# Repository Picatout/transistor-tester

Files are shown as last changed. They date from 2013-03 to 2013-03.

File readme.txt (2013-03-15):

Il s'agit d'un vérificateur de transistor bi-jonction réalisé avec un PIC10F202-I/P

La polarité et l'état du transistor est indiqué par 2 LEDs

Lorsque la LED verte clignote il 'sagit d'un NPN
Lorsque la LED rouge clignote il s'agit d'un PNP
Si les 2 clignotent en alternance il y a un court-circuit entre émetteur et collecteur
Si aucune LED n'allume le transistor est défectueux ou ce n'est pas un transistor bi-jonction.
Si on inverse collecteur et émetteur la LED clignote quand même mais plus faiblement.
Ceci n'indique pas une défectuosité du transistor mais plutôt une certaine symétrie entre les 2 
jonctions, base-collectteur et base-émetteur.  Cette symétrie est particulièrement visible sur
les transistors de commutation ZTX649 (NPN) et ZTX749 (PNP) alors que la LED clignote
avec presqu'autant d'intensité lorsqu'on inverse les émetteurs et collecteurs.

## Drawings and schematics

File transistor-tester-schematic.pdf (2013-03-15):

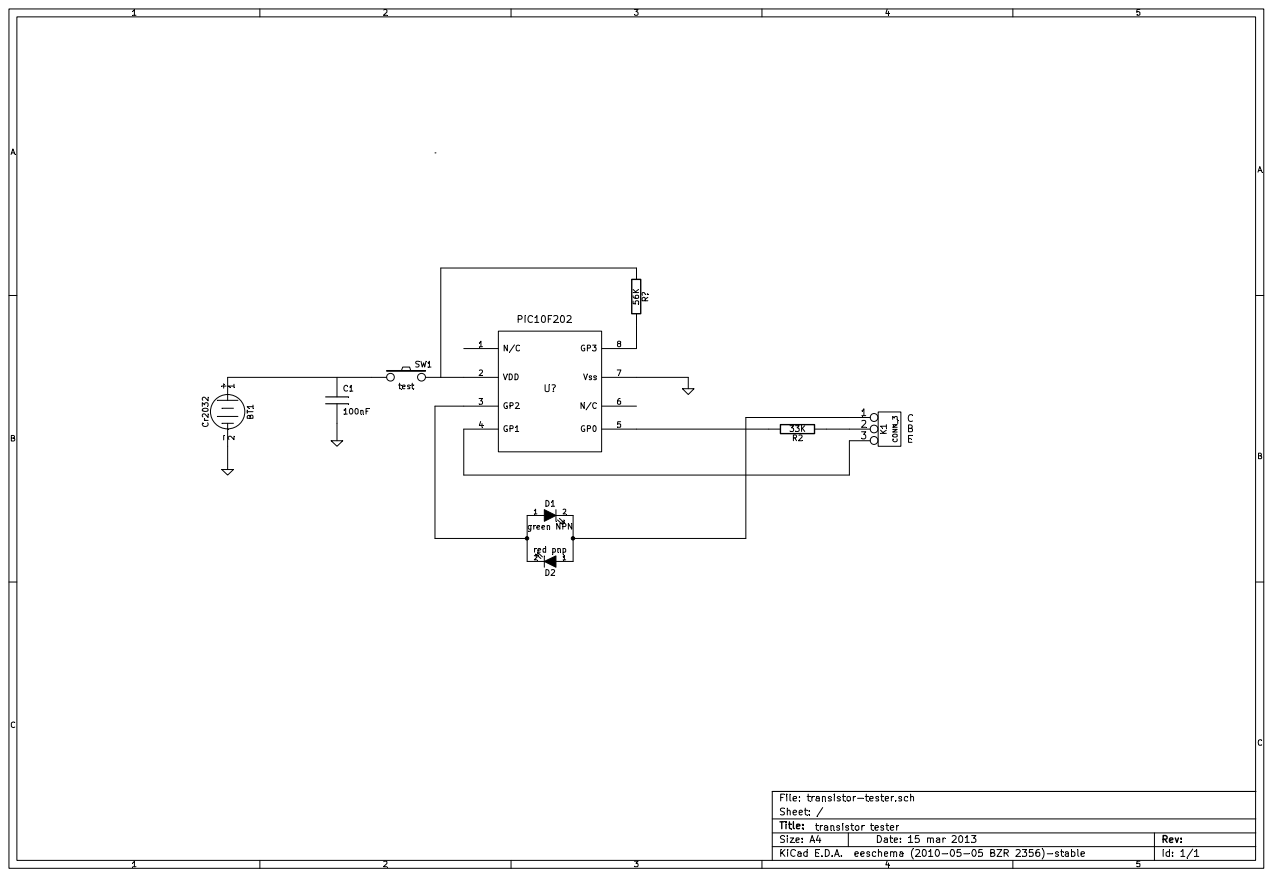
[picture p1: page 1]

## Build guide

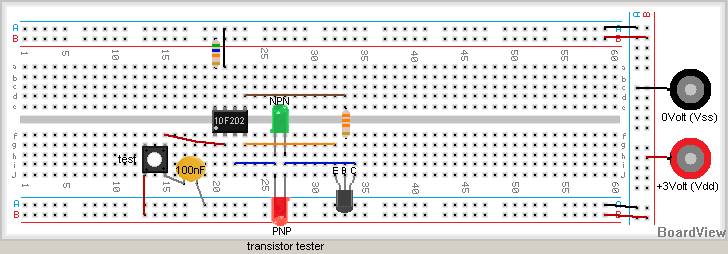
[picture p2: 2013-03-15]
montage-sans-soudure.bmp

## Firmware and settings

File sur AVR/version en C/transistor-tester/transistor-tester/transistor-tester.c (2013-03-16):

/*
 * transistor_tester.c
 *
 * Created: 2013-03-16 10:28:54
 *  Author: Jacques
 * Description: utilise 2 LEDs pour indiquer le type de transistor bi-jonction NPN ou PNP et s'il et en bon état.
 * PB0 contrôle la base du transistor
 * PB3 contrôle l'émetteur
 * PB4 contrôle le collecteur
 */ 

#define F_OSC 1000000 // 1 Mhz

#include <avr/io.h>
#include <util/delay.h>

#define BASE_P PB0
#define EMT_P  PB3
#define COL_P  PB4

#define emt_vss() (PORTB &= ~(1<<EMT_P))
#define emt_vdd() (PORTB |= 1<<EMT_P)
#define col_vss() (PORTB &= ~(1<<COL_P))
#define col_vdd() (PORTB |= 1<<COL_P)
#define base_drive() (DDRB |= 1<<BASE_P)
#define base_hiz() (DDRB &= ~(1<<BASE_P))
#define base_vss() (PORTB&=~(1<<BASE_P))
#define base_vdd() (PORTB|=1<<BASE_P)
  

#define DELAY 250

int main(void)
{
	PORTB = 0;
	DDRB = 1<<EMT_P | 1<<COL_P;
	
    while(1)
    {
       base_hiz();
	   _delay_ms(DELAY);
	   base_drive();
	   // test pour NPN
	   emt_vss();
	   col_vdd();
	   base_vdd();
	   _delay_ms(DELAY);
	   // test pour PNP
	   base_vss();
	   emt_vdd();
	   col_vss();
	   _delay_ms(DELAY);
	           
    }
}

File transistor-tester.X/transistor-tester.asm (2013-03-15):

;NOM: Transistor-tester
;DESCRIPTION: vérificateur de transistor à jonction. Détermine si le transistor
;             est fonctionnel ainsi que son type: NPN ou PNP.
;DATE: 2013-03-15
;AUTEUR: Jacques Deschênes
;MCU: PIC10F200/202
;FONCTIONNEMENT: GP0 contrôle la base à travers une résistance de 33K
;                GP1 est relié à l'émetteur.
;                GP2 est relié au collecteur à travers 2 LED en opposisition.
;                La LED verte clignote lorsqu'un transistor NPN fonctionnel est
;                branché au circuit.
;                La LED rouge clignote lorsqu'un transistor PNP fonctionnel est
;                branché au circuit.
;                Si les 2 LED clignotent en alternance c'est qu'il y a un court-
;                circuuit collecteur-émetteur
;                Une aucune LED n'allume c'est que le transistor est défecteux

    include <P10F202.INC>

    __config _WDTE_OFF& _MCLRE_OFF ; pas de watchdog, pas de reset


;;;;;;;;;;;; constantes ;;;;;;;;;;;;;;;;
BASE_P EQU GP0   ; contrôle base transistor
EMT_P  EQU GP1   ;  émetteur transistor
COL_P  EQU GP2   ;  collecteur transistor

OPTION_CFG EQU  B'11000001' ; TIMER0 contrôlé par Fosc/4, diviseur TMR0=4
                            ; pas de weak pullup, pas de wakeup on pin change.

TRIS_CFG EQU  B'1001' ; GP1 et GP2 en sortie

DELAY EQU D'250'

;;;;;;;;;;;; macros ;;;;;;;;;;;;;;;;;;;;
#define BASE  GPIO, BASE_P
#define EMT   GPIO, EMT_P
#define COL   GPIO, COL_P

emt_vss macro ; met l'émetteur à Vss
   bcf EMT
   endm

emt_vdd macro ; met l'émetteur à Vdd
   bsf EMT
   endm

col_vss macro ; met le collecteur à Vss
   bcf COL
   endm

col_vdd macro ; met le collecteur à Vdd
   bsf COL
   endm

base_drive macro ; met BASE_P en mode sortie
   movlw TRIS_CFG & ~(1<<BASE_P)
   tris GPIO
   endm

base_hiz macro ; met BASE_P en haute impédance
   movlw TRIS_CFG
   tris GPIO
   endm

base_vss macro ; met la base à Vss
   base_drive
   bcf BASE
   endm

base_vdd macro ; met la base à Vdd
   base_drive
   bsf BASE
   endm


_delay_ms macro msec
    movlw msec & H'FF'
    movwf dly_cntr
    movlw (msec>>8)& H'FF'
    movwf dly_cntr+1
    call delay_msec
    endm

;;;;;;;;;;;; variables ;;;;;;;;;;;;;;;;;
    udata
dly_cntr res 2

;;;;;;;;;;;; code ;;;;;;;;;;;;;;;;;;;;;;
rst_vector org 0
    movwf OSCCAL
    goto init

delay_msec
    clrf TMR0
    movlw 5
    addwf TMR0, F
    movfw TMR0
    skpz
    goto $-2
    movlw 1
    subwf dly_cntr, F
    skpnc
    goto delay_msec+1
    subwf dly_cntr+1,F
    skpnc
    goto delay_msec+1
    return

;;;;;;;;;;;; initialisation MCU ;;;;;;;;
init
    movlw OPTION_CFG
    option
    movlw  TRIS_CFG ; GP1 et GP2 en sortie
    tris GPIO


;;;;;;;;;;;; procédure principale ;;;;;;
main
;pas de drive sur la base du transistor
;les 2 LEDS devrait-être éteintes
    _delay_ms DELAY
;test NPN
    emt_vss
    col_vdd
    base_vdd ;LED vert devrait allumé.
    _delay_ms DELAY
    base_hiz ;LED vert devrait éteindre
    _delay_ms DELAY
;test PNP
    emt_vdd
    col_vss
    base_vss ; LED rouge devrait allumé
    _delay_ms DELAY
    base_hiz ; LED rouge devrait éteindre
    end

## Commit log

2013-03-15 vérificateur de transistor réalisé avec un MCU PIC10F202-I/P
    [montage-sans-soudure.brd, transistor-tester.sch]
2013-03-15 remplacement de l'encodage ANSI par unicode UTF-8 dans fichier readme.txt
2013-03-15 correction faute de frappe dans readme.txt
2013-03-15 modification schéma kicad
2013-03-15 moficication fichier boardview
    [montage-sans-soudure.brd]
2013-03-15 modification projet boardview
    [montage-sans-soudure.brd]
2013-03-16 ajout des version AVR8 sur atTiny13A en C et en assembleur
